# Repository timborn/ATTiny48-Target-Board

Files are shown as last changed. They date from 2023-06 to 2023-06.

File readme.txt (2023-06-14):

Wed Jun 14 15:09:53 MST 2023
----------------------------
_X_ add pads for ISP connector
_X_ gotta have an LED to we can detect life
_X_ decoupling caps between VCC and GND
_na pull-up resistor on VCC
    Data sheet section 22, Electrical Characteristics shows the reset pin
    has a built-in pull-up resistor of between 30 and 60 Ohms, so we shouldn't 
    need an external pull-up, especially for a bare bones system.
_X_ noise filtering ckt between VCC and AVCC (so ADC works better)
_X_ pin headers to fit std breadboard
_X_ reset button
_X_ panelize boards
_X_ fix installation of kikit that broke with upgrade of KiCad to 7.0.5

1.  Git Tag each version and make sure you push tags to origin
    https://git-scm.com/book/en/v2/Git-Basics-Tagging
2.  When I went to PCBWAY to place the order, I had panelized 2x4 which ended up
    being 110.5 x 104.7mm.  The price for the boards was $35.  
    When I dropped the size to fit inside 100x100mm the price dropped to $5.
3.  When generating the Gerber files I got a stern warning:
    "Global solder mask minimum width and/or margin are not set to 0.
    Most board manufacturers expect 0 and use their own constraints for
    solder mask minimum width."

    File / Board Setup / Board Stackup / Solder Mask/Paste
    set 'Solder mask expansion' to 0
    set 'Solder mask minimum web width' to 0

    I compared my settings to the requirements from PCBWAY:
    https://www.pcbway.com/pcb_prototype/Pinted_Circuit_Board_Prototype.html
    I didn't find anything about solder mask web width, so I set it at zero
    per KiCad recommendation.  I did change minimum clearance between traces
    to 3mil (0.076mm) per PCBWAY recommendation.  These changes went in post v1.0.

4.  Found a forked trace on pin 22 GND.  Cleaned that up.
5.  Having difficulty with paneling.  Crashes often, and rarely allows me to iterate
    without having to start over with a clean project.  I picked off the command
    line that it builds (uses kikit) but it throws some error when I run it from 
    the command line.  I think I could iterate faster over panels if I had
    the command line stuff working.
6.  ... to that end, I upgraded from KiCad 7.02 to 7.0.5.  I think kikit maybe brew.
    When I installed 7.0.5 over 7.0.2 it went through the motions, but silently failed.
    I had to move the old KiCad folder out of /Applications for installation to complete.
7.  After upgrading to KiCad 7.0.5 it complained about KiKit and sent me here to install it:
    https://github.com/yaqwsx/KiKit/blob/master/doc/installation.md

    Before:
    R2D2:ATTiny48-Target-Board timborn$ kikit --version
    python -m kikit.ui, version 1.3.0

    NB KiCad installed it's own version of Python and kikit, so when I queried pip3
    to see what's up with KiKit, the default version in my PATH didn't know anything
    (which is weird, since I am able to invoke kikit).

    Using the "other" version of Python & friends from KiCad:
    R2D2:test timborn$ /Applications/KiCad/KiCad.app/Contents/Frameworks/Python.framework/Versions/Current/bin/pip3 show kikit

    As I already had the certificate in place ...
    $ curl -O https://raw.githubusercontent.com/yaqwsx/KiKit/master/scripts/installMacOS.bash
    $ sudo bash installMacOS.bash
    
    OK, that got kikit installed (turned out to be the same version).  I just needed to 
    go into KiCad Tools / Plugin and Content Manager and (re-)install kikit.

8. Apparently I have kikit running inside Docker:
   R2D2:test timborn$ docker run  yaqwsx/kikit --version
   I wonder how to use this for panelization.

   $ docker run yaqwsx/kikit panelize     --layout 'hspace: 2mm; vspace: 2mm; cols: 3'\
   --framing 'type: frame' \
   /Volumes/BlueMountain/Users/timborn/kikad/ATTiny48-Target-Board/ATTiny48-Target-Board.kicad_pcb panel.kicad_pcb
   An error occurred: Unable to open /Volumes/BlueMountain/Users/timborn/kikad/ATTiny48-Target-Board/ATTiny48-Target-Board.kicad_pcb for reading.
   No output files produced

   Using bind mount helped!
   # using a bind mount for a local directory so I can pass in the PCB to be panelized
   # and get the results back (the directory on the host in this case is $PWD).
   docker run --mount type=bind,source="$(pwd)",destination=/app yaqwsx/kikit panelize     \
   --layout 'hspace: 2mm; vspace: 2mm; cols: 3'     \
   --framing 'type: frame'     \
   /app/ATTiny48-Target-Board.kicad_pcb \
   /app/panel.kicad_pcb

   KiCad was unable to open this file because it was created with a 
   more recent version than the one you are running.

   Looks like I have to figure out how to update KiCad inside this container.

   OK, I have a clone of yaqwsx/KiKit here:
   /Volumes/BlueMountain/Users/timborn/kikad/KiKit
   In my notes there I see a one-line change to Dockerfile to update to KiCad 7.0:
  
   # ARG KICAD_VERSION="6.0"
   ARG KICAD_VERSION="7.0"

   Build an image called kikit (NOT yaqwsx/kikit):
   Docker build -t kikit .

   Update script.sh to use the correct docker image and Bob's Your Uncle™️

9. 5-8 can be summed up as 1) I upgraded versions of KiCad and KiKit and 
   2) running kikit for paneling inside a Docker container is *way* more
   stable and faster for iterating until you get something you like.

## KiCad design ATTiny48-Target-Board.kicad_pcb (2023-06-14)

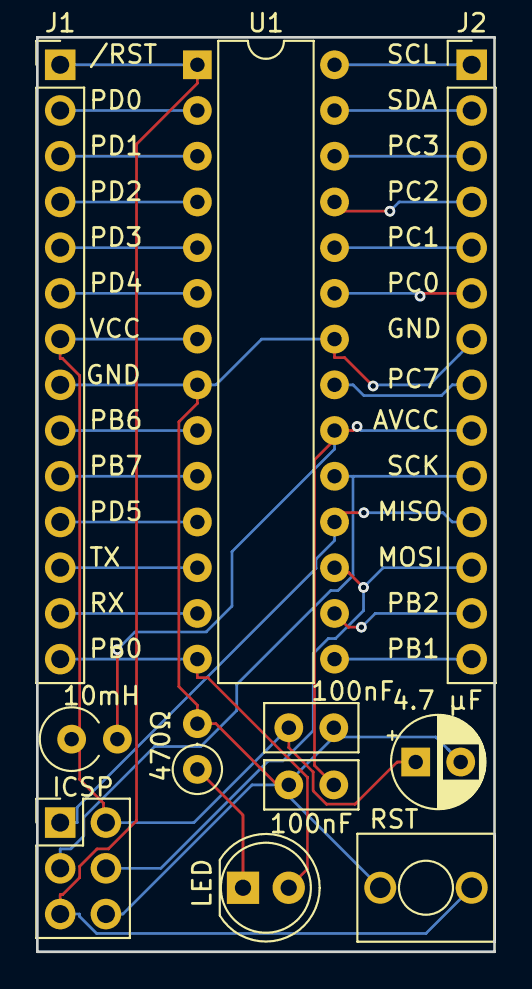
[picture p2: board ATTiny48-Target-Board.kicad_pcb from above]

Board: 2 copper layers, 25.4 x 50.8 mm, 11 parts (0 on the bottom side), 28 nets.

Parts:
4.7 µF: 4.7 uF; CP_Radial_D5.0mm_P2.50mm
10mH: 10 mH; L_Axial_L7.0mm_D3.3mm_P2.54mm_Vertical_Fastron_MICC
100nF, 100nF#2: 100 nF; C_Disc_D5.0mm_W2.5mm_P2.50mm
470Ω: 470; R_Axial_DIN0207_L6.3mm_D2.5mm_P2.54mm_Vertical
ICSP: AVR-ISP-6; PinHeader_2x03_P2.54mm_Vertical
J1, J2: Conn_01x14_Pin; PinHeader_1x14_P2.54mm_Vertical
LED: LED; LED_D5.0mm
RST: SW_Push; TDB_Tayda_Tactile_SPST
U1: ATtiny48-P; DIP-28_W7.62mm

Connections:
AVCC: 10mH.2, 100nF.2, J2.9, U1.20 (AVCC)
GND: 4.7 µF.2, 100nF.1, 100nF#2.2, 470Ω.2, ICSP.6 (GND), J1.8, J2.7, RST.1, U1.8 (GND), U1.22 (GND)
unnamed: 470Ω.1, LED.1 (K)
PB0: J1.14, LED.2 (A), U1.14 (PB0)
PB1: J2.14, U1.15 (PB1)
PB2: J2.13, U1.16 (PB2)
PB3: ICSP.4 (MOSI), J2.12, U1.17 (PB3)
PB4: ICSP.1 (MISO), J2.11, U1.18 (PB4)
PB5: ICSP.3 (SCK), J2.10, U1.19 (PB5)
PB6: J1.9, U1.9 (PB6)
PB7: J1.10, U1.10 (PB7)
PC0: J2.6, U1.23 (PC0)
PC1: J2.5, U1.24 (PC1)
PC2: J2.4, U1.25 (PC2)
PC3: J2.3, U1.26 (PC3)
PC4: J2.2, U1.27 (PC4)
PC5: J2.1, U1.28 (PC5)
PC7: J2.8, U1.21 (PC7)
PD0: J1.2, U1.2 (PD0)
PD1: J1.3, U1.3 (PD1)
PD2: J1.4, U1.4 (PD2)
PD3: J1.5, U1.5 (PD3)
PD4: J1.6, U1.6 (PD4)
PD5: J1.11, U1.11 (PD5)
PD6: J1.12, U1.12 (PD6)
PD7: J1.13, U1.13 (PD7)
RESET: ICSP.5 (~RST), J1.1, RST.2, U1.1 (~RESET/PC6)
VCC: 4.7 µF.1, 10mH.1, 100nF#2.1, ICSP.2 (VCC), J1.7, U1.7 (VCC)

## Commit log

2023-06-13 Made a compact 25.4 x 50.8mm board with space for ATtiny44/48, a reset button, an LED, ICSP connector, and proper noise decoupling between VCC and AVCC. A decent start on a useful bit of common boile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
    Not included:
    1. external crystal. The internal one is fine until it's not.
    So far I haven't found the need.
    2. USB connector. Once I figure out how to add serial I/O and program
    over the USB connector (preferably USB-C) I will add it, but I don't
    know how. Yet.
    NB the reset button is (apparently) non-standard, in that it's two pin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
    [ATTiny48-Target-Board.kicad_pcb, ATTiny48-Target-Board.kicad_sch, ATTiny48-Target-Board.sch]
2023-06-13 v1.0 ready to be paneled and sent to fab
    [ATTiny48-Target-Board.kicad_pcb, ATTiny48-Target-Board.kicad_sch]
2023-06-14 v1.1 change hinky trace on pin 22
    [ATTiny48-Target-Board.kicad_pcb, ATTiny48-Target-Board.kicad_sch]
2023-06-14 gerbers after panelizing
